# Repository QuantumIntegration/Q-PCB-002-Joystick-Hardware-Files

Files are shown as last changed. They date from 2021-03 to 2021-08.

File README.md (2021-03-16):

# Quantum DIY Kit Hardware Files - Joystick
## Introduction

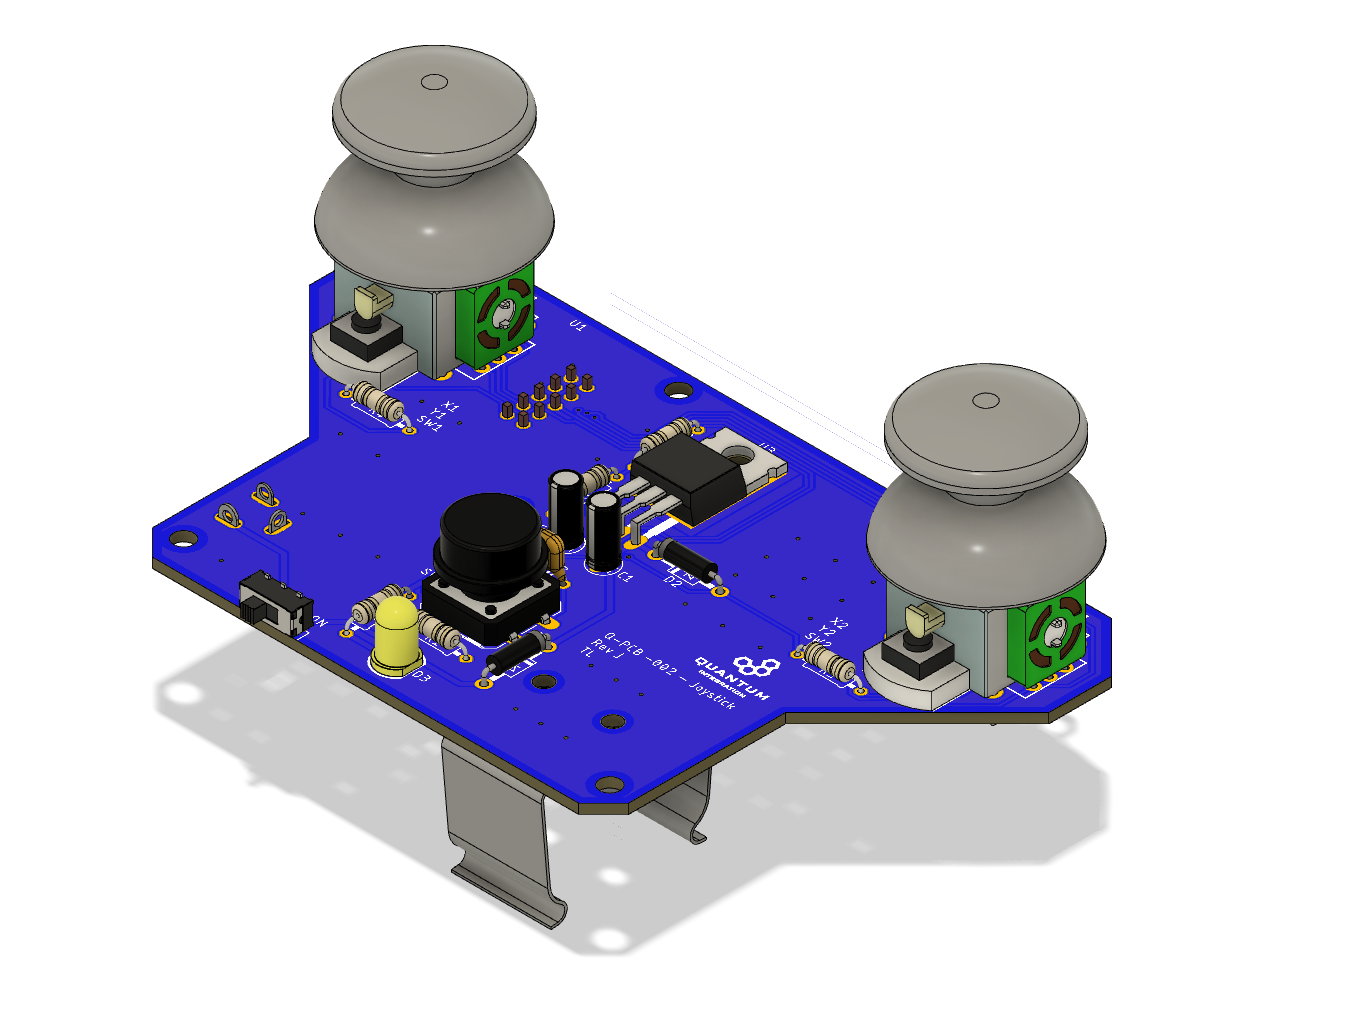
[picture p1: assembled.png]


This repository contains all the hardware files necessary to build the PCBs and assemble the DIY kits. The PCBs can be ordered from for example [JLCPCB](https://jlcpcb.com/) or [PCBWay](https://www.pcbway.com/). The components can be sourced mostly from [Amazon](https://amazon.com/) or [Digikey](https://digikey.com/), according to the links in the BOM file.

## Download the correct revision

If you are nor familiar with the git version control system, please follow these simple steps to download your version of the DIY kit

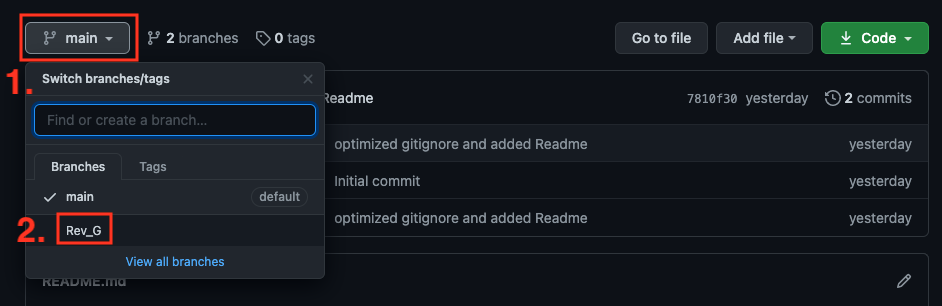
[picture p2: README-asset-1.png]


<em>1. Click the branch button</em>

<em>2. Select the branch matching your revision</em>

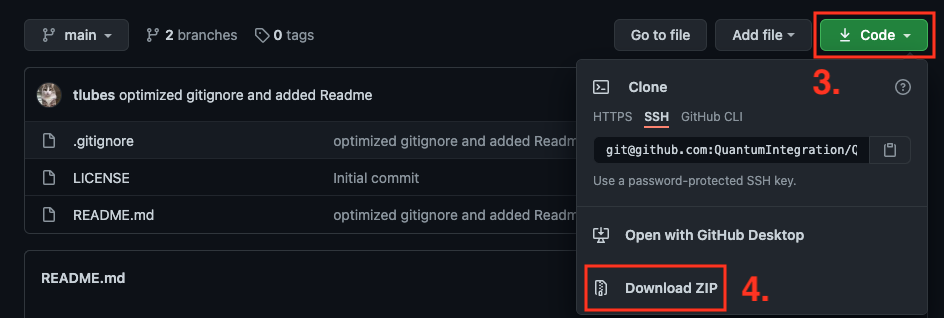
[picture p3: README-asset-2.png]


<em>3. Click the Code button</em>

<em>4. Download the ZIP and extract it on your machine</em>

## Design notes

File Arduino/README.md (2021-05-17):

# Example for Arduino usage
## Usage

The example is intended to work with the Q-PCB-003 Four Motor board. Follow the instructions below to connect the Joystick to the Arduino.

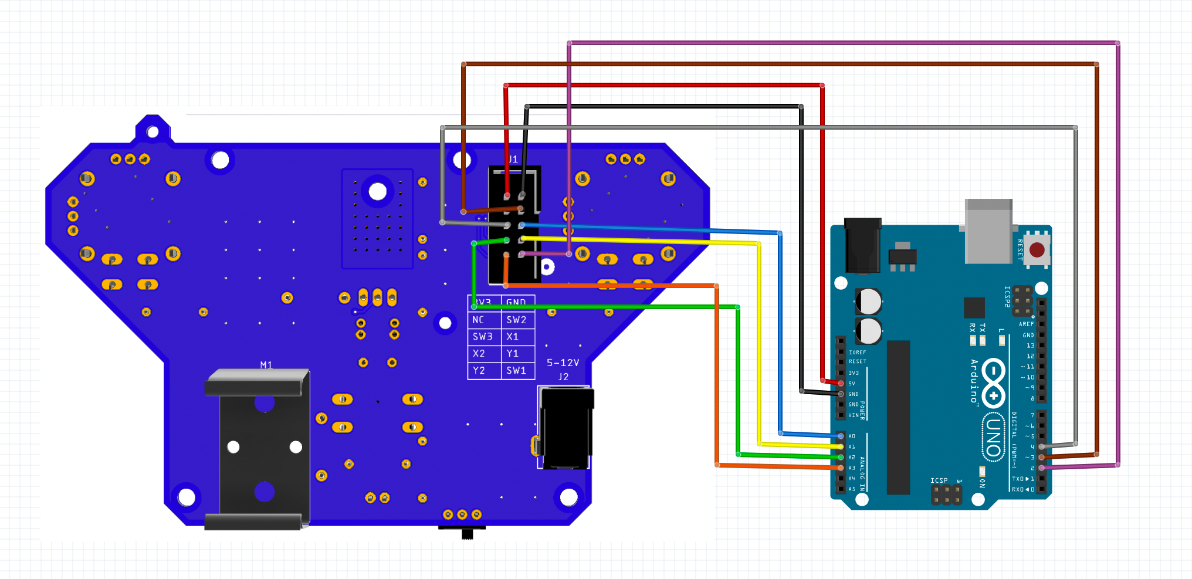
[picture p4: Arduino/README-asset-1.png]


The graphic below shows how two Arduinos get connected together via I2C.

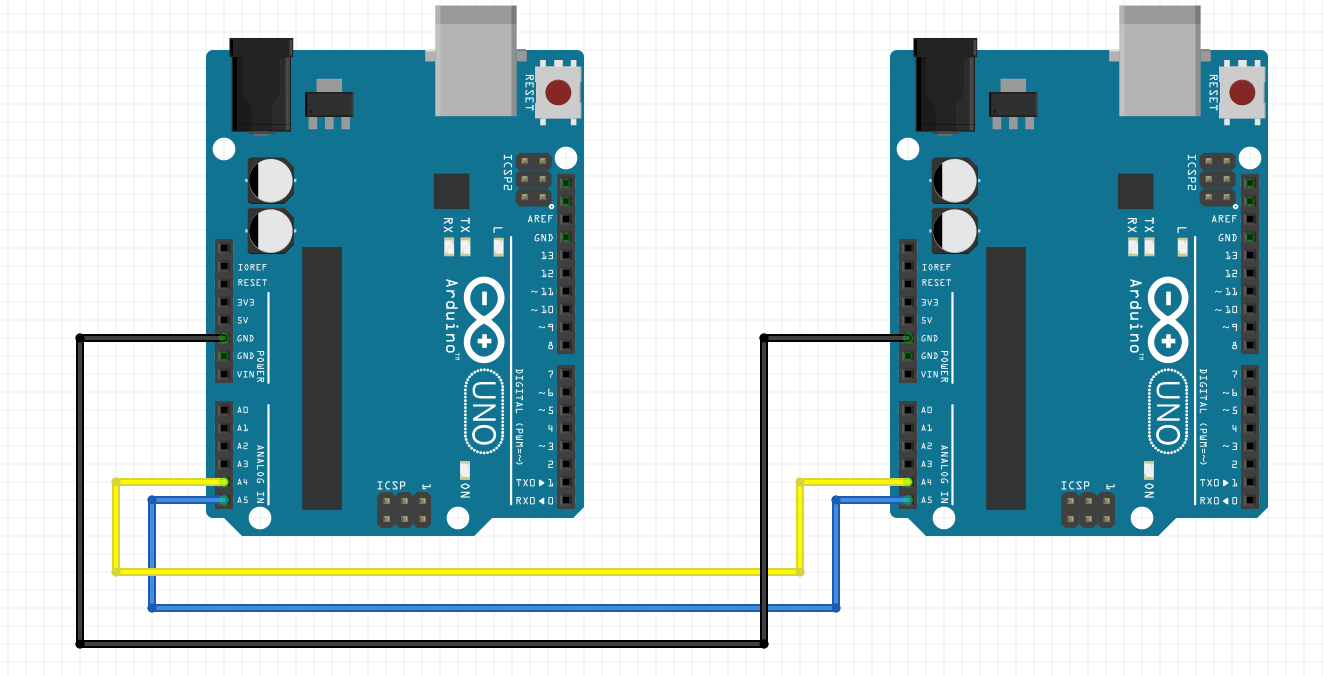
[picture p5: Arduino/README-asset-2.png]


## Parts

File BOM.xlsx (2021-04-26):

Index | Part | Value | Quantity | Designators | Package | Comments | Specific Part Reference | Part Link Example
1 | Joystick |  | 2 | U1, U2 |  | Large Button Spacing |  | https://www.digikey.com/product-detail/en/sparkfun-electronics/COM-09032/1568-1526-ND/6823623
2 | Barrell Jack |  | 1 | J2 |  | 2.1mm jack |  | https://www.digikey.com/products/en?keywords=694106301002
3 | Battery Holder |  | 1 | M1 |  | horizontal M3 holes |  | https://www.digikey.com/product-detail/en/keystone-electronics/79/36-79-ND/316812
4 | Ribbon Connector |  | 1 | J1 |  | 2x5, keyed, male |  | https://www.digikey.com/product-detail/en/on-shore-technology-inc/302-S101/ED1543-ND/2178422
5 | Slide Switch |  | 1 | S2 |  | 90 degree | EG1270 | https://www.digikey.com/product-detail/en/e-switch/EG1270/EG1847-ND/6076
6 | Tactile Button |  | 1 | S1 | B3F-40xx | black round color cap | Omron B3F-4055, Black round Cap | https://www.digikey.com/product-detail/en/omron-electronics-inc-emc-div/B3F-4055/SW414-ND/31799
7 | Electrolytic Capacitor | 220n | 1 | C1 | E2-4 | H: 8mm, 50V |  | https://www.digikey.com/product-detail/en/nichicon/USP1H0R1MDD/493-15992-ND/2539178
8 | Ceramic Capacitor | 100n | 1 | C3 | 024x044 |  |  | https://www.digikey.com/product-detail/en/kemet/C315C104M5U5TA7303/399-9859-1-ND/3726100
9 | Diode | 1N4001 | 2 | D1, D2 |  |  |  | https://www.digikey.com/product-detail/en/comchip-technology/1N4001-G/641-1310-3-ND/1979654
10 | Electrolytic Capacitor | 1u | 1 | C2 | E2-4 | H: 8mm, 50V |  | https://www.digikey.com/product-detail/en/nichicon/USA1H010MDD1TE/493-14556-3-ND/4994224
11 | Resistor | 240 | 1 | R5 | 0207/10 | 1/4 W |  | https://www.amazon.com/SIQUK-Resistors-Resistor-Assortment-Experiments/dp/B07PTNN78Z
12 | Resistor | 390 | 1 | R6 | 0207/10 | 1/4 W |  | https://www.amazon.com/SIQUK-Resistors-Resistor-Assortment-Experiments/dp/B07PTNN78Z
13 | Resistor | 4.7k | 1 | R2 | 0207/10 | 1/4 W |  | https://www.amazon.com/SIQUK-Resistors-Resistor-Assortment-Experiments/dp/B07PTNN78Z
14 | LED | green-diffused | 1 | D3 | 5mm |  |  | https://www.amazon.com/Diffused-Lighting-Electronics-Components-Emitting/dp/B01C3ZZU3G
15 | LM317 |  | 1 | U3 | TO-220-3 |  | LM317T | https://www.digikey.com/product-detail/en/stmicroelectronics/LM317T/497-1575-5-ND/591677
16 | Resistor | 10k | 3 | R1, R3, R4 | 0207/10 | 1/4 W |  | https://www.amazon.com/SIQUK-Resistors-Resistor-Assortment-Experiments/dp/B07PTNN78Z
17 | Battery Harness |  | 1 |  |  | 2.1 mm plug |  | https://www.amazon.com/AKOAK-Battery-Button-Connector-Holder/dp/B01E9TXP7M
18 | M2 Standoff |  | 2 |  |  | 15mm, Female-Female |  | https://www.amazon.com/gp/product/B07CNF3W7B/ref=ppx_yo_dt_b_asin_title_o01_s00?ie=UTF8&psc=1
19 | M2 Screw |  | 4 |  |  | 5mm |  | https://www.amazon.com/gp/product/B07CNF3W7B/ref=ppx_yo_dt_b_asin_title_o01_s00?ie=UTF8&psc=1
20 | M2.5 Screw |  | 2 |  |  | 6mm |  | https://www.amazon.com/gp/product/B075K3QBMX/ref=ppx_yo_dt_b_search_asin_title?ie=UTF8&psc=1
21 | M2.5 Nut |  | 2 |  |  |  |  | https://www.amazon.com/gp/product/B075K3QBMX/ref=ppx_yo_dt_b_search_asin_title?ie=UTF8&psc=1
22 | M3 Screw |  | 5 |  |  | 6mm |  | https://www.amazon.com/gp/product/B07CNF3W7B/ref=ppx_yo_dt_b_asin_title_o01_s00?ie=UTF8&psc=1
23 | M3 Nut |  | 1 |  |  |  |  | https://www.amazon.com/gp/product/B07CNF3W7B/ref=ppx_yo_dt_b_asin_title_o01_s00?ie=UTF8&psc=1
24 | RIbbon Cable |  | 1 |  |  | rainbow colored |  | https://www.amazon.com/uxcell-Rainbow-Ribbon-Connector-19-7inch/dp/B07T2V3GNC?s=hi
25 | Ribbon End Piece |  | 1 |  |  | keyed |  | https://www.amazon.com/uxcell-Rainbow-Ribbon-Connector-19-7inch/dp/B07T2V3GNC?s=hi
26 | M4 Screw |  | 2 |  |  | 8mm |  | https://www.amazon.com/gp/product/B07CNF3W7B/ref=ppx_yo_dt_b_asin_title_o01_s00?ie=UTF8&psc=1
27 | Thermal Pad with fitting |  | 1 |  |  | fits LM317 |  | https://www.digikey.com/product-detail/en/bergquist/HF115AC-0-0055-AC-54/BER167-ND/307789

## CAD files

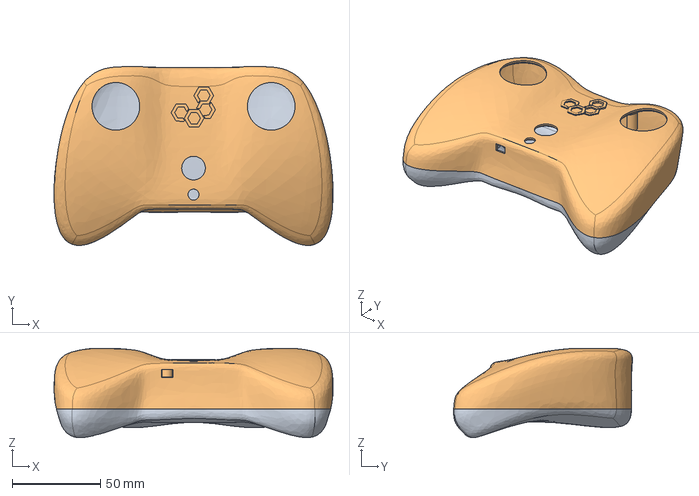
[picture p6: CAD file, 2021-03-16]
Case/Case.step
158.0 x 101.4 x 50.6 mm

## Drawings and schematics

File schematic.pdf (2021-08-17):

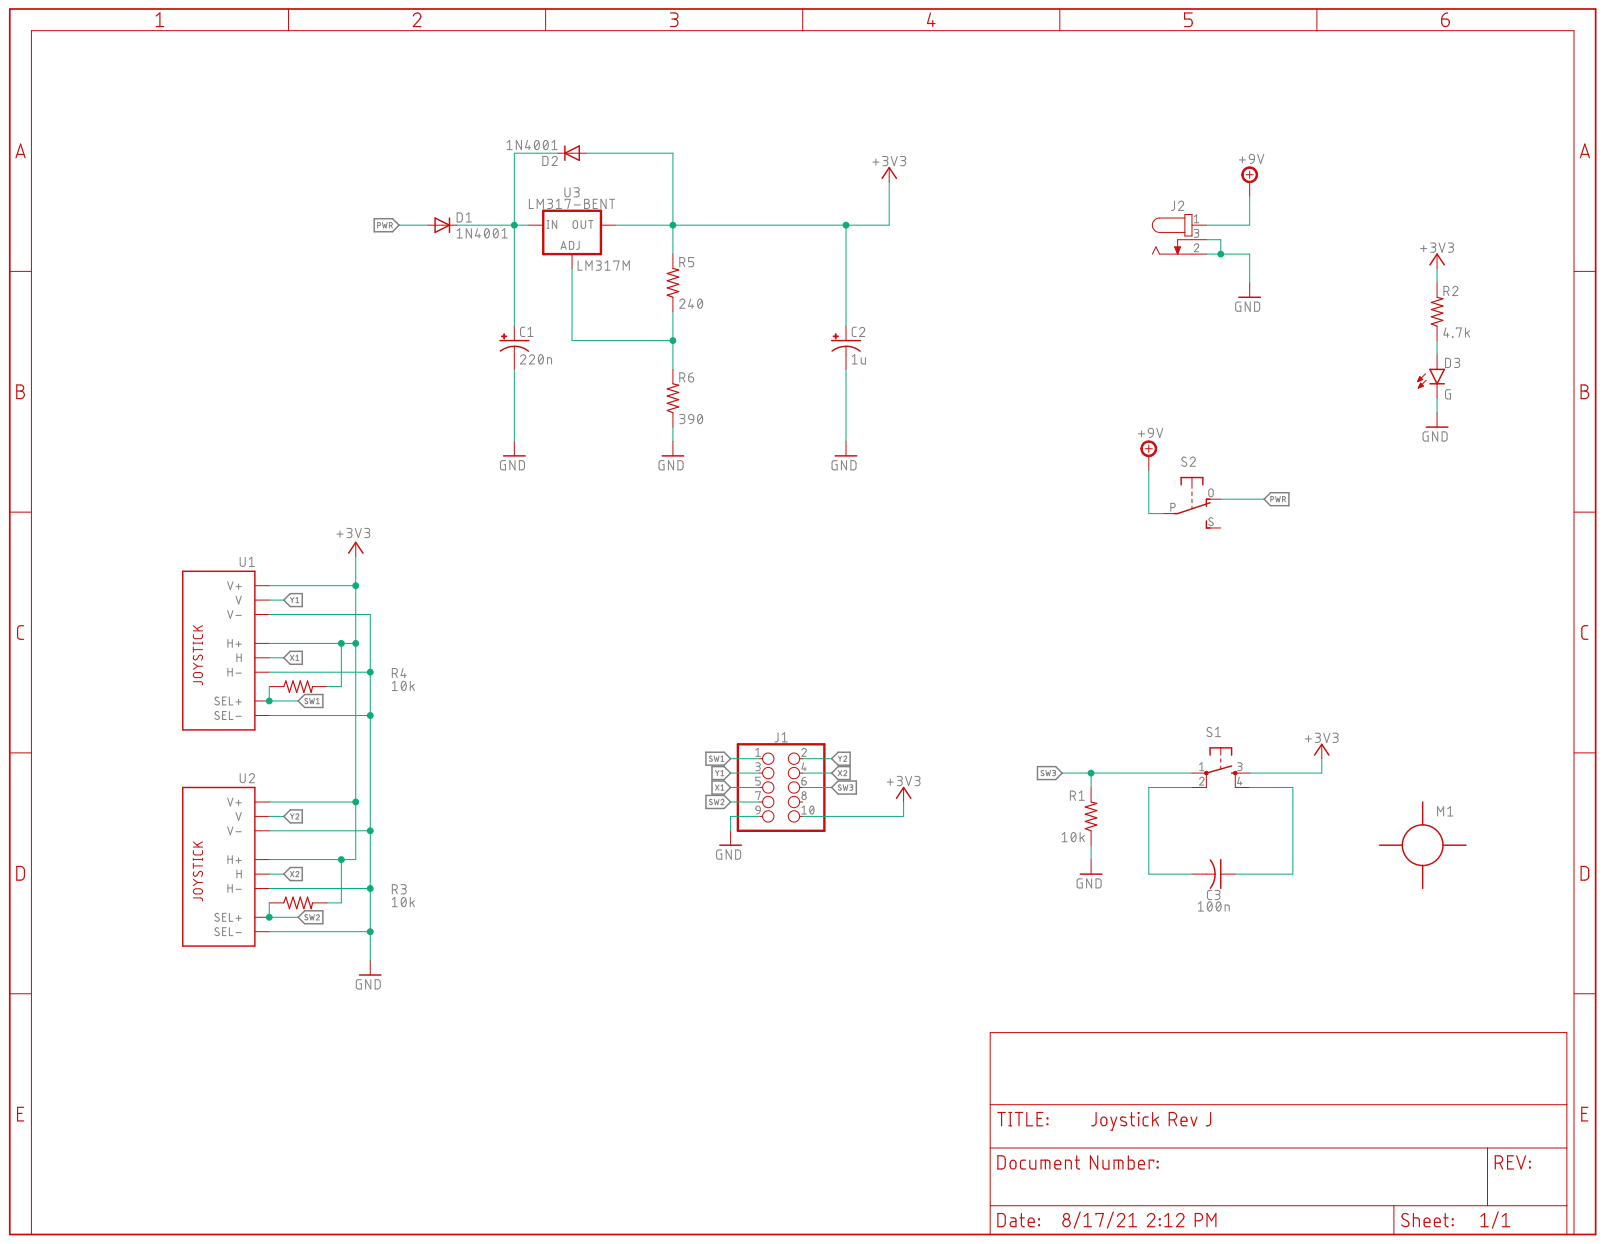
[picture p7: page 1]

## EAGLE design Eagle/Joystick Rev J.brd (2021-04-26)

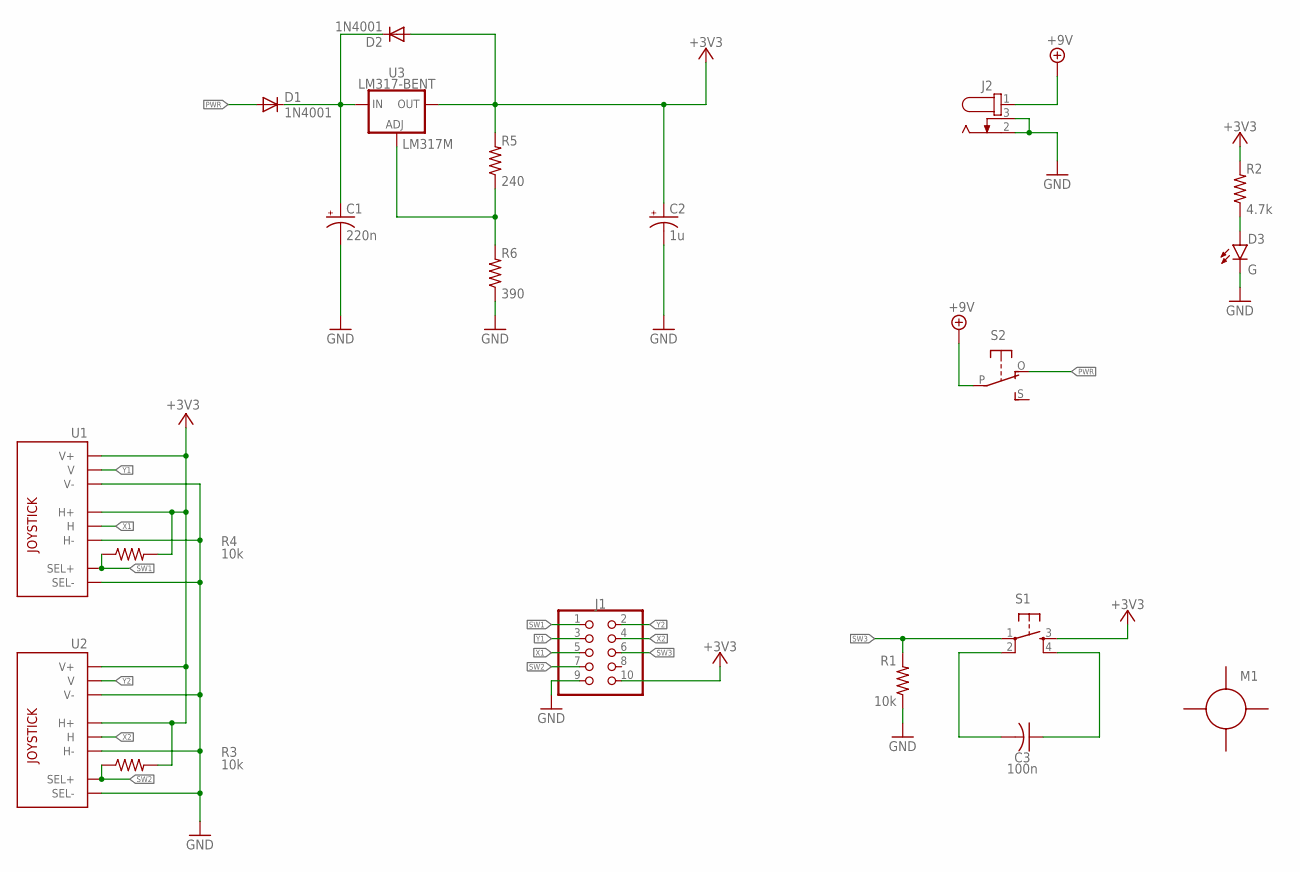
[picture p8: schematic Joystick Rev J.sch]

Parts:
C1: 220n; E2-4
C2: 1u; E2-4
C3: 100n; C050-024X044
D1, D2: 1N4001; DO41-10
D3: G; LED5MM
J1: RIBBON-2X5; 057-010-1
J2: 694106301002
M1: 9V-HOLDERM2.5; 9V-HOLDER-M2.5
R1, R3, R4: 10k; 0207/10
R2: 4.7k; 0207/10
R5: 240; 0207/10
R6: 390; 0207/10
S1: TACTILE-BUTTON40XX; B3F-40XX
S2: SLIDE-SWITCHSIDE; EG1270-90
U1, U2: JOYSTICK
U3: LM317-BENT; T03B; PARTNUMBER LM317M

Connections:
+3V3: C2.+, D2.A, J1.10, R2.2, R3.2, R4.2, R5.2, S1.3 (S), U1.H1 (H+), U1.V1 (V+), U2.H1 (H+), U2.V1 (V+), U3.2 (OUT)
+9V: J2.1, S2.P
GND: C1.-, C2.-, D3.K (C), J1.9, J2.2, J2.3, R1.1, R6.1, U1.B2A (SEL-), U1.H3 (H-), U1.V3 (V-), U2.B2A (SEL-), U2.H3 (H-), U2.V3 (V-)
unnamed: R5.1, R6.2, U3.1 (ADJ)
unnamed: D3.A, R2.1
unnamed: C3.1, S1.4 (S1)
unnamed: C3.2, S1.2 (P1)
unnamed: C1.+, D1.C, D2.C, U3.3 (IN)
PWR: D1.A, S2.O
SW1: J1.1, R4.1, U1.B1A (SEL+)
SW2: J1.7, R3.1, U2.B1A (SEL+)
SW3: J1.6, R1.2, S1.1
X1: J1.5, U1.H2 (H)
X2: J1.4, U2.H2 (H)
Y1: J1.3, U1.V2 (V)
Y2: J1.2, U2.V2 (V)

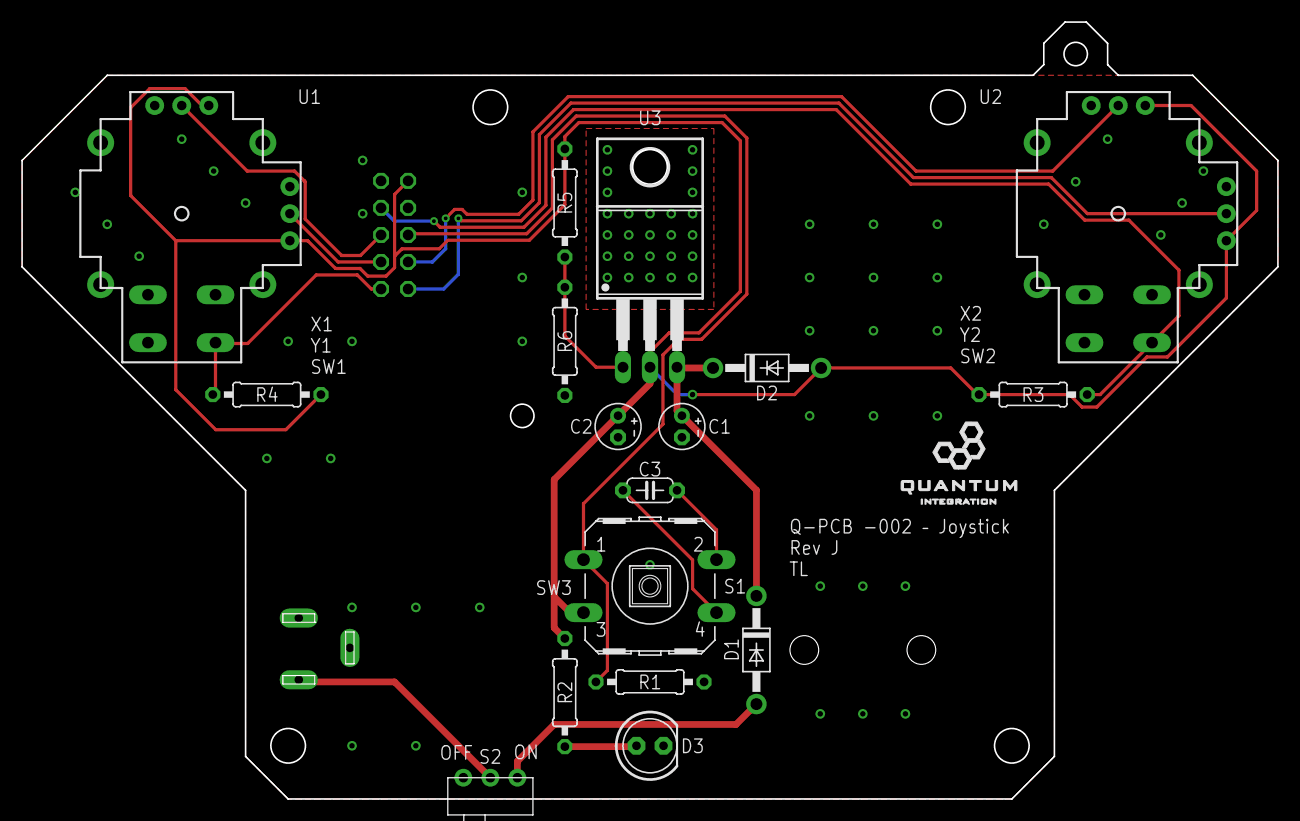
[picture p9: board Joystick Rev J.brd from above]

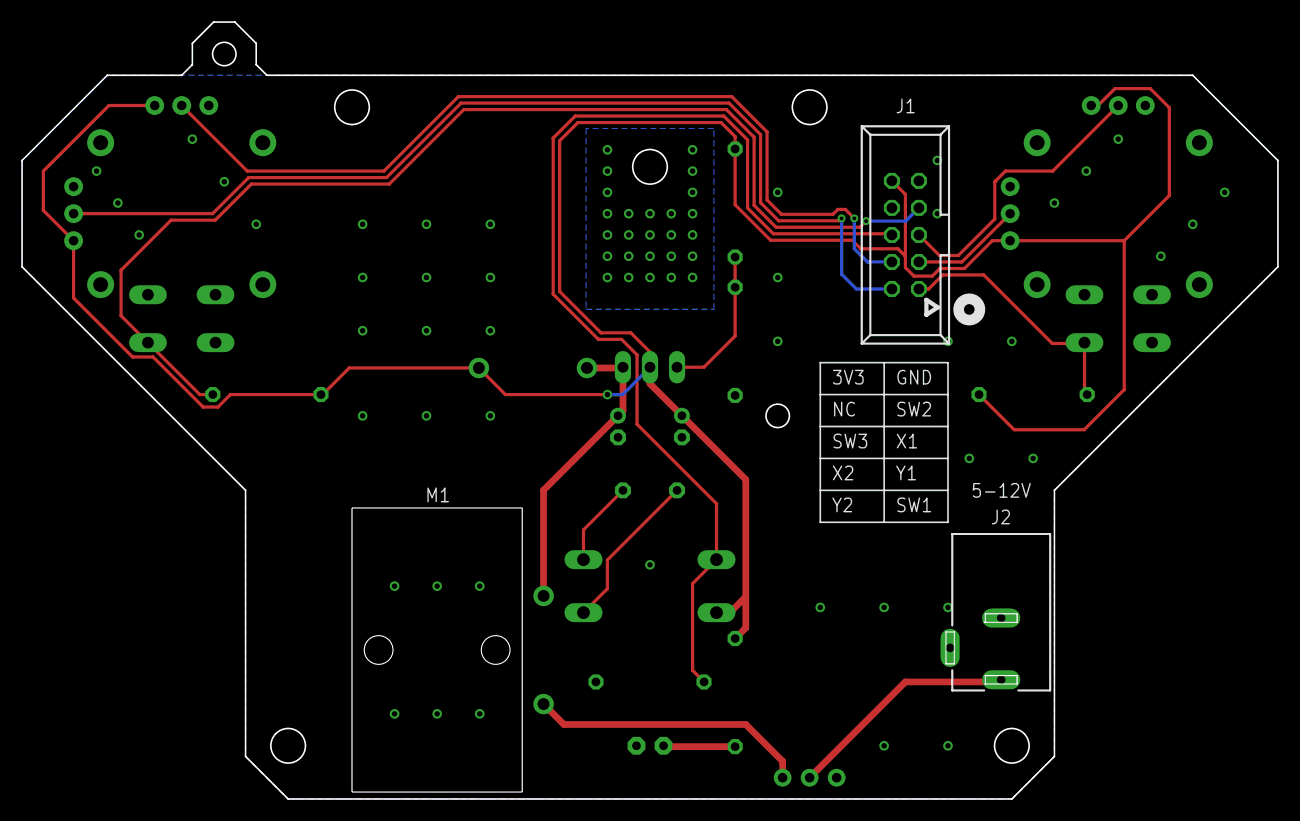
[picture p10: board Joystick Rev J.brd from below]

Board: 2 copper layers, 118.0 x 73.0 mm, 20 parts (3 on the bottom side), 16 nets.

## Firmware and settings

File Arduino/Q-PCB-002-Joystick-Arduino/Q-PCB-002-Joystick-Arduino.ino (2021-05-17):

// Tim Lubes
// Quantum Integration, 2021

#include "Wire.h"

// uncomment for debug information
// #define DEBUG

#ifdef DEBUG
  #define DEBUG_P(...) Serial.print(__VA_ARGS__)
  #define DEBUG_PLN(...) Serial.println(__VA_ARGS__)
#else
  #define DEBUG_P(...)
  #define DEBUG_PLN(...)
#endif

#define JOYSTICK_1_X   A0
#define JOYSTICK_1_Y   A1
#define JOYSTICK_1_SW  2
#define JOYSTICK_2_X   A2 
#define JOYSTICK_2_Y   A3
#define JOYSTICK_2_SW  3  
#define TACTILE_SW     4  

struct {
  uint16_t joystick_1_x;  
  uint16_t joystick_1_y;         
  bool joystick_1_sw;
  uint16_t joystick_2_x;  
  uint16_t joystick_2_y;         
  bool joystick_2_sw;
  bool tactile_sw;         
} joystick_output;            // saves the joystick output data 
              
void setup() {
  Serial.begin(115200); 
  pinMode(JOYSTICK_1_X, INPUT);
  pinMode(JOYSTICK_1_Y, INPUT);
  pinMode(JOYSTICK_1_Y, INPUT); 
  pinMode(JOYSTICK_2_X, INPUT);
  pinMode(JOYSTICK_2_Y, INPUT);
  pinMode(JOYSTICK_2_Y, INPUT);
  pinMode(TACTILE_SW, INPUT);
  
  Wire.begin();
}

void loop() {
  
  joystick_output.joystick_1_x = analogRead(JOYSTICK_1_X);
  joystick_output.joystick_1_y = analogRead(JOYSTICK_1_Y);
  joystick_output.joystick_1_sw  = !digitalRead(JOYSTICK_1_SW);  // Invert the pulldown switch
  joystick_output.joystick_2_x  = analogRead(JOYSTICK_2_X);
  joystick_output.joystick_2_y  = analogRead(JOYSTICK_2_Y);
  joystick_output.joystick_2_sw =  !digitalRead(JOYSTICK_2_SW);  // Invert the pulldown switch
  joystick_output.tactile_sw = digitalRead(TACTILE_SW);

  DEBUG_P(joystick_output.joystick_1_x);
  DEBUG_P(",");
  DEBUG_P(joystick_output.joystick_1_y);
  DEBUG_P(",");
  DEBUG_P(joystick_output.joystick_1_sw);
  DEBUG_P(",");
  DEBUG_P(joystick_output.joystick_2_x);
  DEBUG_P(",");
  DEBUG_P(joystick_output.joystick_2_y);
  DEBUG_P(",");
  DEBUG_P(joystick_output.joystick_2_sw); 
  DEBUG_P(",");
  DEBUG_PLN(joystick_output.tactile_sw); 
  
  Wire.beginTransmission(0x22);
  Wire.write((uint8_t*) &joystick_output, sizeof(joystick_output));
  Wire.endTransmission();
    
  delay(100);
}

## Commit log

2021-03-16 added project content
    [BOM.xlsx, Case.step, Josytick Rev J.sch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]
2021-04-26 changes to BOM for manufacturing
    [BOM.xlsx, Joystick Rev J.brd, Joystick Rev J.sch]
2021-05-17 added Arduino files
2021-08-17 added schematic as PDF

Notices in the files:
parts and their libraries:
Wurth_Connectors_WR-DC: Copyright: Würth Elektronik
